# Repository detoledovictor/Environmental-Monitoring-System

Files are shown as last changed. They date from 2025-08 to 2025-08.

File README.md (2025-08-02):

# Environmental Monitoring System

This project is a real-time environmental and motion monitoring system based on the ESP32 with FreeRTOS. It features a TFT display, Wi-Fi connectivity, temperature and acceleration sensing, and visual status indication via an RGB LED.

## 🔧 Features

- 📶 Wi-Fi connection with automatic reconnection
- 🌐 NTP time synchronization (UTC-3)
- 🌡️ Temperature reading (BMP280)
- 🧭 3-axis acceleration monitoring (MMA8452Q)
- 🖥️ 240x240 TFT display with 7-segment styled digital clock
- 🎨 Graphical display of data with FreeRTOS-controlled tasks
- 🔴🟡🟢 RGB LED status indicator using FastLED

## ⚙️ Architecture

- Multitasking with FreeRTOS (`TaskWiFiConnect`, `TaskDateTime`, `TaskReadSensors`, etc.)
- Inter-task communication via `QueueHandle_t`
- Display rendering protected by `SemaphoreHandle_t`

## 📚 Dependencies

- [TFT_eSPI](https://github.com/Bodmer/TFT_eSPI)
- [FastLED](https://github.com/FastLED/FastLED)
- [Adafruit BMP280 Library](https://github.com/adafruit/Adafruit_BMP280_Library)
- [RoboCore MMA8452Q](https://github.com/RoboCore/MMA8452Q)
- `WiFi.h`, `NTPClient.h`, `Wire.h`, `SPI.h`

## 📦 Hardware

- ESP32 Dev Module
- 1x TFT 240x240 display (SPI)
- 1x BMP280 sensor (I2C)
- 1x MMA8452Q accelerometer (I2C)
- 1x RGB LED (Neopixel - GPIO 19)

## 📸 Preview

> [Add image or GIF here of the display in action]

## 🛠️ Setup

1. Install libraries listed above via Library Manager or git.
2. Connect peripherals according to pin mapping.
3. Set your Wi-Fi credentials in the code (`ssid`, `password`).
4. Upload using Arduino IDE or PlatformIO.

## 📄 License

MIT License

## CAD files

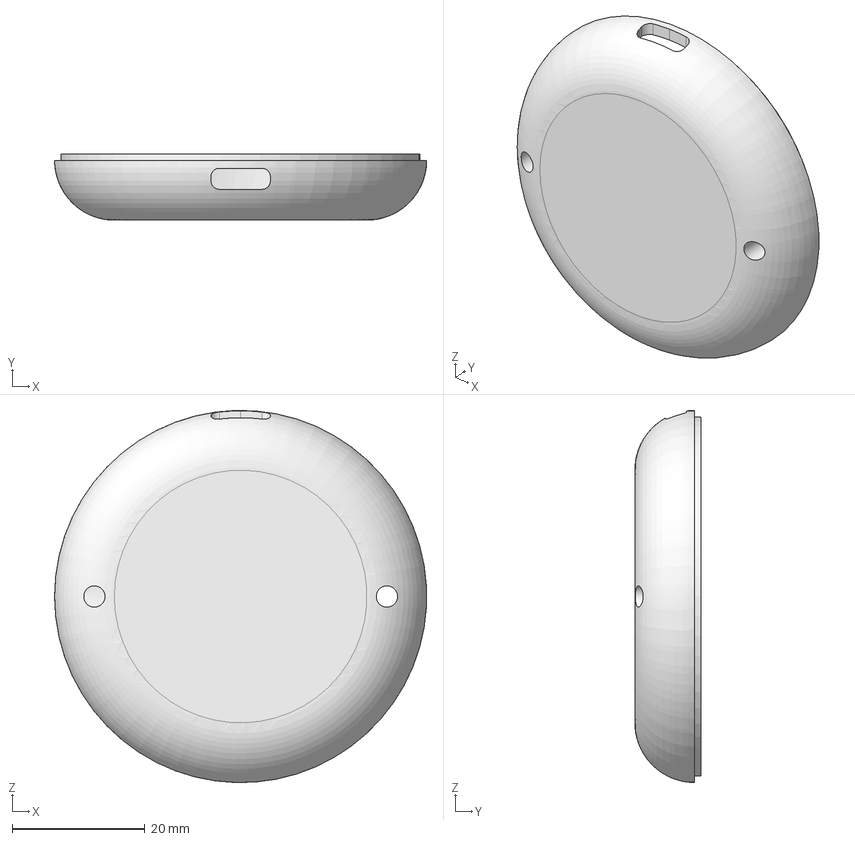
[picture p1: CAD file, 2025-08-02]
MCAD/moldura_001-BASE.step
56.0 x 10.00 x 56.0 mm

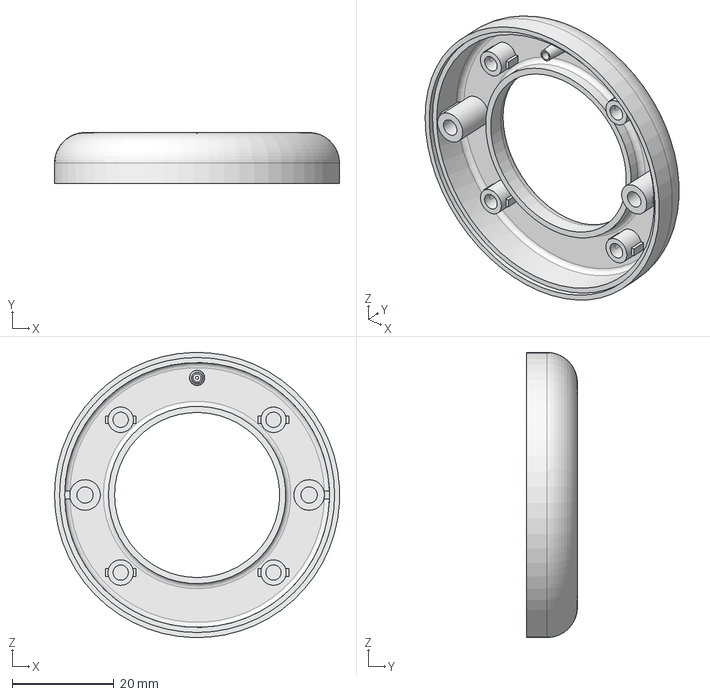
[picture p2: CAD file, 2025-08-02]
MCAD/moldura_001-TAMPA.step
56.0 x 10.0 x 56.0 mm

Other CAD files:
MCAD/Environmental Monitoring Enclosure.FCStd
MCAD/moldura_001-BASE.stl
MCAD/moldura_001-TAMPA.stl

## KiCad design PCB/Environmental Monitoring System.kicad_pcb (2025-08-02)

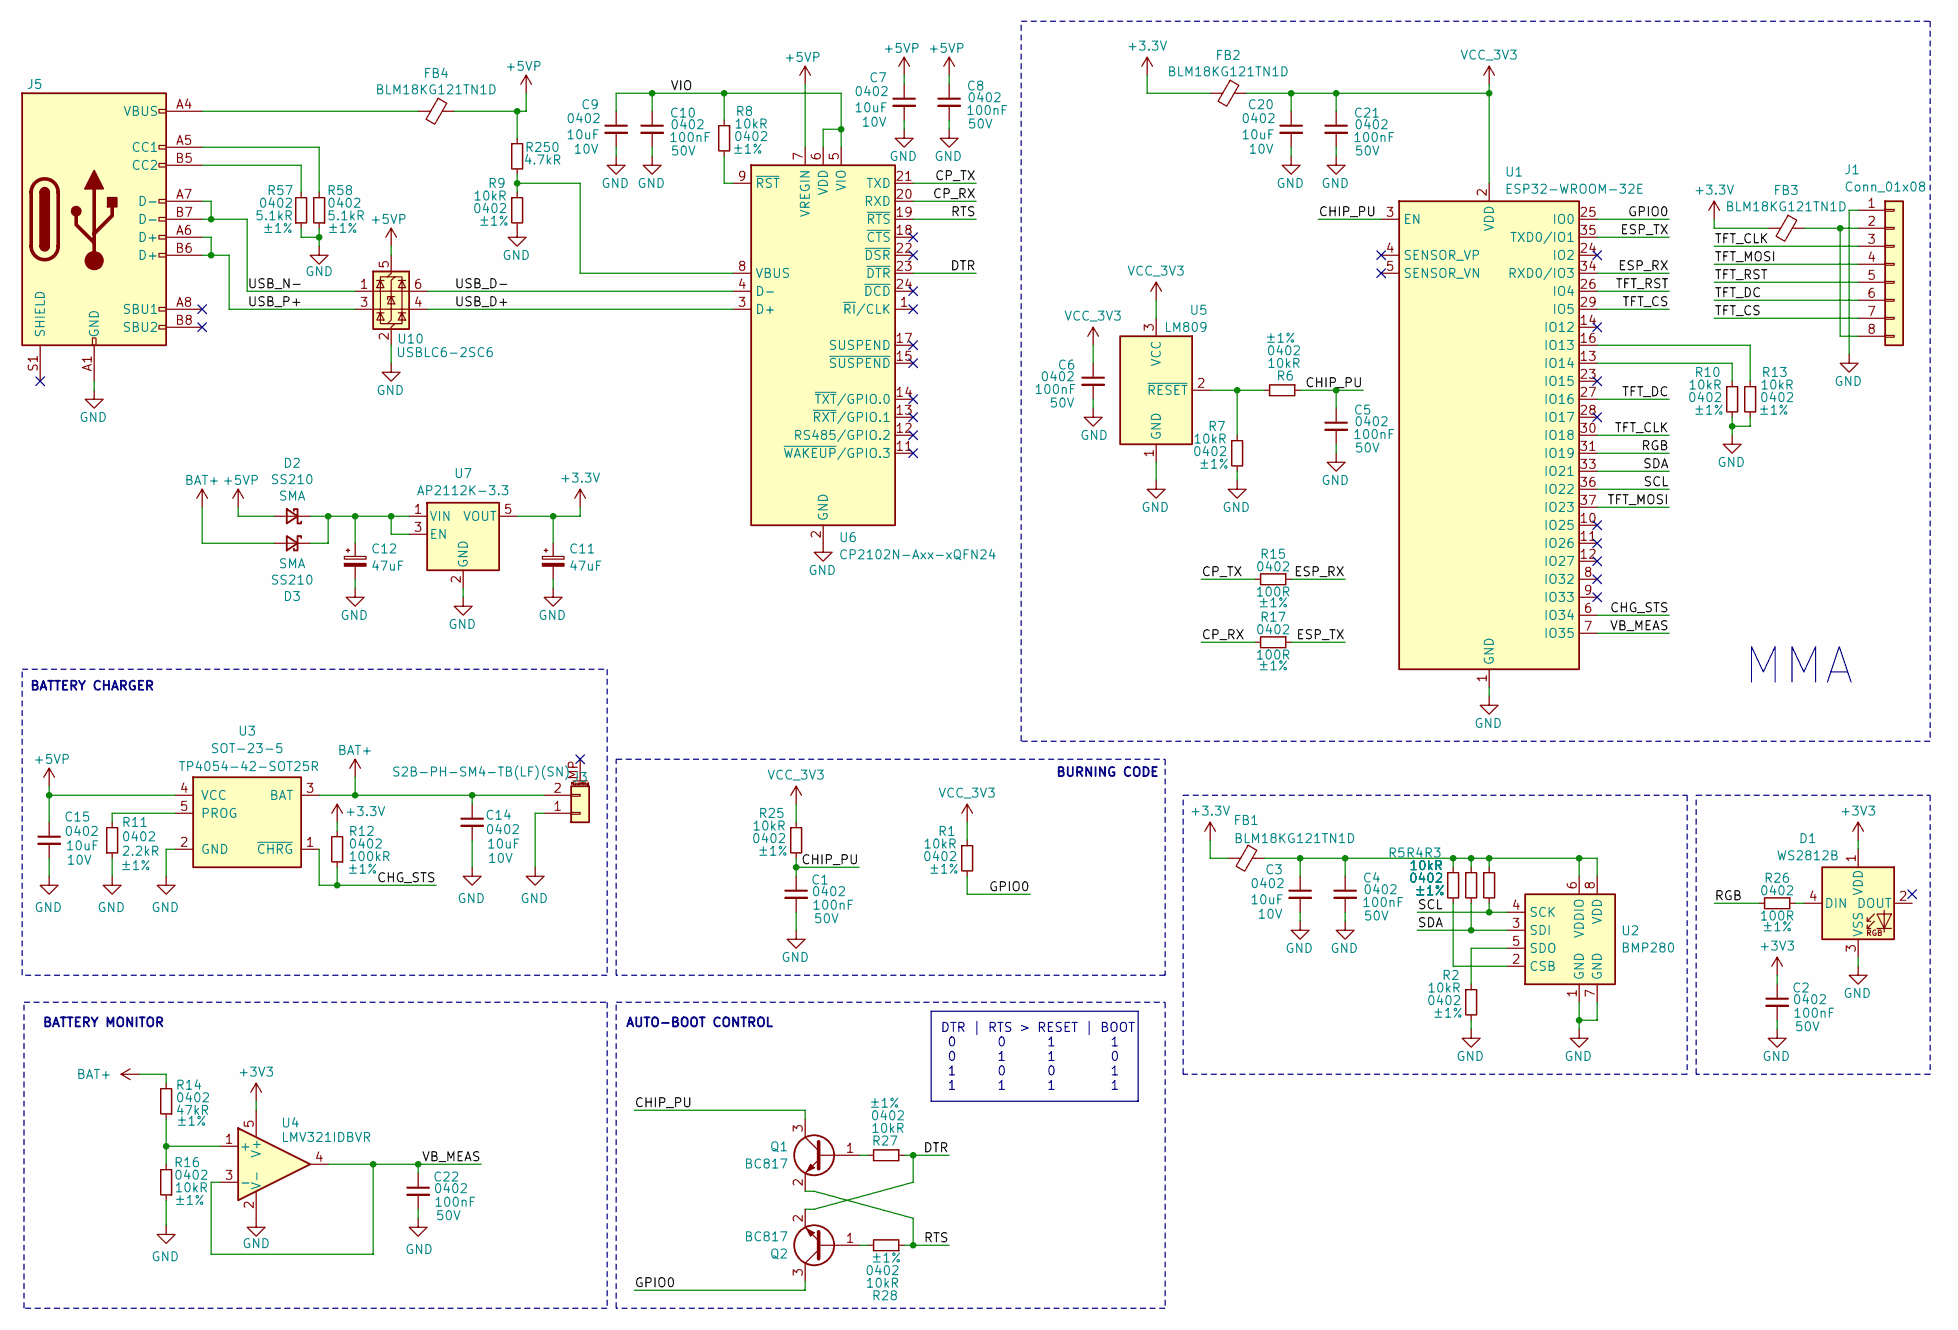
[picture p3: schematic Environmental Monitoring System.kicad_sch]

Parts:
C1, C2, C4, C5, C6, C8, C10, C21, C22: 100nF; C_0402_1005Metric; Voltage 50V; Part CL05B104KB5NNNC; LCSC C960916
C3, C7, C9, C14, C15, C20: 10uF; C_0402_1005Metric; Voltage 10V; Part CL05A106MP5NUNC; LCSC C315248
C11, C12: 47uF; CP_EIA-3216-18_Kemet-A
D1: WS2812B; LED_WS2812B-Mini_PLCC4_3.5x3.5mm
D2, D3: SS210; D_SMA; Voltage 100V; Part SS210; LCSC C14996
FB1, FB2, FB3, FB4: BLM18KG121TN1D; L_0603_1608Metric; Part BLM18KG121TN1D; LCSC C85831
J1: Conn_01x08; PinHeader_1x08_P2.54mm_Vertical
J3: S2B-PH-SM4-TB(LF)(SN); JST_PH_B2B-PH-K_1x02_P2.00mm_Vertical; Part S2B-PH-SM4-TB(LF)(SN); LCSC C295747
J5: USB_C_Receptacle_USB2.0_16P; USB_C_Receptacle_GCT_USB4105-xx-A_16P_TopMnt_Horizontal; Part TYPE-C 16PIN 2MD(073); LCSC C2765186
Q1, Q2: BC817; SOT-23
R1, R2, R3, R4, R5, R6, R7, R8, R9, R10, R13, R16, R25, R27, R28: 10KR; R_0402_1005Metric; Tolerance ±1%; Part 0402WGF1002TCE; LCSC C25744
R11: 2.2KR; R_0402_1005Metric; Tolerance ±1%; Part 0402WGF2201TCE; LCSC C25879
R12: 100KR; R_0402_1005Metric; Tolerance ±1%; Part 0402WGF1003TCE; LCSC C25741
R14: 47KR; R_0402_1005Metric; Tolerance ±1%; Part 0402WGF4702TCE; LCSC C25792
R15, R17, R26: 100R; R_0402_1005Metric; Tolerance ±1%; Part 0402WGF1000TCE; LCSC C25076
R57, R58: 5.1KR; R_0402_1005Metric; Tolerance ±1%; Part 0402WGF5101TCE; LCSC C25905
R250: 4.7kR; R_0402_1005Metric; Tolerance ±1%; Part 0402WGF4701TCE; LCSC C25900
U1: ESP32-WROOM-32E; ESP32-WROOM-32D
U2: BMP280; Bosch_LGA-8_2x2.5mm_P0.65mm_ClockwisePinNumbering
U3: TP4054; SOT-23-5; Part TP4054-42-SOT25R; LCSC C32574
U4: LMV321; SOT-23-5; Part LMV321IDBVR; LCSC C3014306
U5: LM809; SOT-23
U6: CP2102N-Axx-xQFN24; QFN-24-1EP_4x4mm_P0.5mm_EP2.6x2.6mm; Part CP2102N-A02-GQFN24R; LCSC C969151
U7: AP2112K-3.3; SOT-23-5
U10: USBLC6-2SC6; SOT-23-6; Part USBLC6-2SC6; LCSC C7519

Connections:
+3.3V: C11.1, FB1.2, FB2.2, FB3.2, R12.2, U7.5 (VOUT)
+3V3: C2.1, D1.1 (VDD), U4.5 (V+)
+5VP: C7.1, C8.1, C15.1, D2.2 (A), FB4.1, R250.1, U3.4 (VCC), U6.7 (VREGIN), U10.5 (VBUS)
/CHG_STS: R12.1, U1.6 (IO34), U3.1 (~CHRG)
/CHIP_PU: C1.1, C5.1, Q1.3 (C), R6.1, R25.2, U1.3 (EN)
/CP_RX: R17.2, U6.20 (RXD)
/CP_TX: R15.2, U6.21 (TXD)
/DTR: Q2.2 (E), R27.1, U6.23 (~DTR)
/ESP_RX: R15.1, U1.34 (RXD0/IO3)
/ESP_TX: R17.1, U1.35 (TXD0/IO1)
/GPIO0: Q2.3 (C), R1.2, U1.25 (IO0)
/RGB: R26.2, U1.31 (IO19)
/RTS: Q1.2 (E), R28.1, U6.19 (~RTS)
/SCL: R3.2, U1.36 (IO22), U2.4 (SCK)
/SDA: R4.2, U1.33 (IO21), U2.3 (SDI)
/TFT_CLK: J1.3, U1.30 (IO18)
/TFT_CS: J1.7, U1.29 (IO5)
/TFT_DC: J1.6, U1.27 (IO16)
/TFT_MOSI: J1.4, U1.37 (IO23)
/TFT_RST: J1.5, U1.26 (IO4)
/USB_D+: U6.3 (D+), U10.4 (I/O2)
/USB_D-: U6.4 (D-), U10.6 (I/O1)
/USB_N-: J5.A7 (D-), J5.B7 (D-), U10.1 (I/O1)
/USB_P+: J5.A6 (D+), J5.B6 (D+), U10.3 (I/O2)
/VB_MEAS: C22.1, U1.7 (IO35), U4.3 (-), U4.4
/VIO: C9.1, C10.1, R8.1, U6.5 (VIO), U6.6 (VDD)
BAT+: C14.1, D3.2 (A), J3.2, R14.2, U3.3 (BAT)
GND: C1.2, C2.2, C3.2, C4.2, C5.2, C6.2, C7.2, C8.2, C9.2, C10.2, C11.2, C12.2, C14.2, C15.2, C20.2, C21.2, C22.2, D1.3 (VSS), J1.1, J3.1, J5.A1 (GND), J5.A12 (GND), J5.B1 (GND), J5.B12 (GND), R2.2, R7.2, R9.2, R10.2, R11.1, R13.2, R16.1, R57.1, R58.1, U1.1 (GND), U1.15 (GND), U1.38 (GND), U1.39 (GND), U2.1 (GND), U2.7 (GND), U3.2 (GND), U4.2 (V-), U5.1 (GND), U6.2 (GND), U6.25 (GND), U7.2 (GND), U10.2 (GND)
unnamed: D1.4 (DIN), R26.1
unnamed: C12.1, D2.1 (K), D3.1 (K), U7.1 (VIN), U7.3 (EN)
unnamed: FB4.2, J5.A4 (VBUS), J5.A9 (VBUS), J5.B4 (VBUS), J5.B9 (VBUS)
unnamed: FB3.1, J1.2, J1.8
unnamed: J5.A5 (CC1), R58.2
unnamed: J5.B5 (CC2), R57.2
unnamed: Q1.1 (B), R27.2
unnamed: Q2.1 (B), R28.2
unnamed: R13.1, U1.16 (IO13)
unnamed: R10.1, U1.13 (IO14)
unnamed: R5.2, U2.2 (CSB)
unnamed: R2.1, U2.5 (SDO)
unnamed: C3.1, C4.1, FB1.1, R3.1, R4.1, R5.1, U2.6 (VDDIO), U2.8 (VDD)
unnamed: R11.2, U3.5 (PROG)
unnamed: R14.1, R16.2, U4.1 (+)
unnamed: R6.2, R7.1, U5.2 (~RESET)
unnamed: R9.1, R250.2, U6.8 (VBUS)
unnamed: R8.2, U6.9 (~RST)
VCC_3V3: C6.1, C20.1, C21.1, FB2.1, R1.1, R25.1, U1.2 (VDD), U5.3 (VCC)

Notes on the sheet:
DTR | RTS > RESET | BOOT 0 0 1 1 0 1 1 0 1 0 0 1 1 1 1 1
BATTERY CHARGER
AUTO-BOOT CONTROL
BURNING CODE
MMA
BATTERY MONITOR

Board: 2 copper layers, 61 parts (4 on the bottom side), 47 nets, no tracks yet.

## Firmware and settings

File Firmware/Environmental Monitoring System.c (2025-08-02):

#include <Arduino.h>
#include "freertos/FreeRTOS.h"
#include "freertos/task.h"
#include "freertos/queue.h"
#include "freertos/semphr.h"
#include <Wire.h>
#include <SPI.h>
#include <TFT_eSPI.h>
#include "RoboCore_MMA8452Q.h"
#include <Adafruit_BMP280.h>
#include <WiFi.h>
#include <NTPClient.h>
#include <WiFiUdp.h>
#include <FastLED.h>

// Configurações do Display TFT
TFT_eSPI tft = TFT_eSPI(240, 240);

// Configurações do LED RGB
#define NUM_LEDS 1
#define DATA_PIN 19
#define LED_UPDATE_INTERVAL 50  // ms
CRGB leds[NUM_LEDS];

// Configurações Wi-Fi
const char *ssid = "[Your_SSID]";
const char *password = "[YOUR_PASSWORD]";

// Configurações NTP
WiFiUDP ntpUDP;
NTPClient timeClient(ntpUDP, "pool.ntp.org", -3 * 3600);  // UTC-3 (Brasília)

// Arrays para dias da semana
String diasSemana[] = { "Dom", "Seg", "Ter", "Qua", "Qui", "Sex", "Sab" };

MMA8452Q accelerometer;
Adafruit_BMP280 bmp;

// Estrutura para dados do display
typedef struct {
  String line1;  // Data e hora
  String line2;  // Temperatura
  float accel_x;
  float accel_y;
  float accel_z;
  String line6;  // Status WiFi
} DisplayData;

// Fila para comunicação entre tarefas
QueueHandle_t displayQueue;
DisplayData currentDisplayData;  // Mantém o estado atual do display

SemaphoreHandle_t displayMutex = xSemaphoreCreateMutex();

// Protótipos das tarefas
void TaskBlink(void *pvParameters);
void TaskReadSensors(void *pvParameters);
void TaskWiFiConnect(void *pvParameters);
void TaskDateTime(void *pvParameters);
void TaskUpdateDisplay(void *pvParameters);
void TaskUpdateLED(void *pvParameters);

// Protótipos das funções de desenho
void desenharHorarioSegmentos(const String &timeStr);
void desenharData(const String &dateStr);
void desenharTempUmidade(const String &tempStr);
void desenharAcelerometro(float x, float y, float z);
void desenharIndicadorAcelerometro(float x, float y);
void desenharDigito7Seg(int digito, int x, int y);

void setup() {
  Serial.begin(115200);
  pinMode(2, OUTPUT);

  // Inicializa o LED RGB
  FastLED.addLeds<NEOPIXEL, DATA_PIN>(leds, NUM_LEDS);
  leds[0] = CRGB::Black;
  FastLED.show();

  // Inicializa I2C
  Wire.begin(21, 22);  // SDA, SCL

  // Inicializa o display TFT
  tft.begin();
  tft.setRotation(0);
  tft.fillScreen(TFT_BLACK);

  // Inicializa o acelerômetro
  if (!accelerometer.init()) {
    Serial.println("Falha na inicialização do acelerômetro");
    while (1)
      ;
  }

  // Inicializa o BMP280
  if (!bmp.begin(0x76)) {
    Serial.println("Falha na inicialização do BMP280!");
    while (1)
      ;
  }

  // Cria a fila para o display
  displayQueue = xQueueCreate(5, sizeof(DisplayData));

  // Inicializa a estrutura de dados do display
  currentDisplayData = DisplayData();

  // Cria as tarefas
  xTaskCreate(TaskBlink, "Blink", 2048, NULL, 1, NULL);
  xTaskCreate(TaskReadSensors, "Sensors", 4096, NULL, 2, NULL);
  xTaskCreate(TaskWiFiConnect, "WiFiConnect", 8192, NULL, 3, NULL);
  xTaskCreate(TaskDateTime, "DateTime", 4096, NULL, 2, NULL);
  xTaskCreate(TaskUpdateDisplay, "Display", 4096, NULL, 3, NULL);
  xTaskCreate(TaskUpdateLED, "LED", 2048, NULL, 2, NULL);
}

void loop() {
  // Nada aqui - tudo é tratado pelas tarefas
}

// Tarefa: Piscar LED onboard
void TaskBlink(void *pvParameters) {
  for (;;) {
    digitalWrite(2, !digitalRead(2));
    vTaskDelay(500 / portTICK_PERIOD_MS);
  }
}

// Tarefa: Leitura de sensores
void TaskReadSensors(void *pvParameters) {
  DisplayData data;

  for (;;) {
    // Lê acelerômetro
    accelerometer.read();
    data.accel_x = accelerometer.x;
    data.accel_y = accelerometer.y;
    data.accel_z = accelerometer.z;

    // Lê temperatura
    float temperature = bmp.readTemperature();
    data.line2 = String(temperature, 1);

    // Envia dados para a fila
    xQueueSend(displayQueue, &data, portMAX_DELAY);

    vTaskDelay(100 / portTICK_PERIOD_MS);
  }
}

// Tarefa: Conexão Wi-Fi
void TaskWiFiConnect(void *pvParameters) {
  DisplayData data;

  data.line6 = "Conectando WiFi...";
  xQueueSend(displayQueue, &data, portMAX_DELAY);

  WiFi.begin(ssid, password);

  int attempts = 0;
  while (WiFi.status() != WL_CONNECTED && attempts < 20) {
    vTaskDelay(500 / portTICK_PERIOD_MS);
    Serial.print(".");
    attempts++;
  }

  if (WiFi.status() == WL_CONNECTED) {
    data.line6 = "WiFi OK";
    xQueueSend(displayQueue, &data, portMAX_DELAY);

    // Mantém a conexão ativa
    for (;;) {
      if (WiFi.status() != WL_CONNECTED) {
        WiFi.reconnect();
        data.line6 = "Reconectando...";
        xQueueSend(displayQueue, &data, portMAX_DELAY);
        vTaskDelay(5000 / portTICK_PERIOD_MS);
      }
      vTaskDelay(1000 / portTICK_PERIOD_MS);
    }
  } else {
    data.line6 = "WiFi Falhou!";
    xQueueSend(displayQueue, &data, portMAX_DELAY);
    vTaskDelay(5000 / portTICK_PERIOD_MS);
    ESP.restart();
  }
}

// Tarefa: Data e Hora
void TaskDateTime(void *pvParameters) {
  DisplayData data;

  // Espera conexão Wi-Fi
  while (WiFi.status() != WL_CONNECTED) {
    vTaskDelay(1000 / portTICK_PERIOD_MS);
  }

  timeClient.begin();

  for (;;) {
    timeClient.update();

    // Formata data e hora
    String dayOfWeek = diasSemana[timeClient.getDay()];
    time_t epochTime = timeClient.getEpochTime();
    struct tm *ptm = gmtime(&epochTime);

    // Formata a hora (HH:MM)
    int hours = timeClient.getHours();
    int minutes = timeClient.getMinutes();
    String formattedTime = String(hours < 10 ? "0" : "") + String(hours) + ":" + String(minutes < 10 ? "0" : "") + String(minutes);

    // Formata a data (DD/MM/YYYY)
    String formattedDate = String(ptm->tm_mday) + "/" + String(ptm->tm_mon + 1) + "/" + String(ptm->tm_year + 1900);

    // Combina tudo
    data.line1 = formattedTime + "|" + dayOfWeek + "," + formattedDate;

    xQueueSend(displayQueue, &data, portMAX_DELAY);
    vTaskDelay(1000 / portTICK_PERIOD_MS);
  }
}

// Tarefa: Atualização centralizada do display
void TaskUpdateDisplay(void *pvParameters) {
  DisplayData newData;
  unsigned long lastUpdate = 0;
  const unsigned long updateInterval = 10;  // ms

  for (;;) {
    unsigned long now = millis();

    // Verifica se há novos dados na fila
    if (xQueueReceive(displayQueue, &newData, 0) == pdTRUE) {
      // Atualiza apenas os campos que receberam novos dados
      if (!newData.line1.isEmpty()) currentDisplayData.line1 = newData.line1;
      if (!newData.line2.isEmpty()) currentDisplayData.line2 = newData.line2;
      if (newData.accel_x != 0 || newData.accel_y != 0 || newData.accel_z != 0) {
        currentDisplayData.accel_x = newData.accel_x;
        currentDisplayData.accel_y = newData.accel_y;
        currentDisplayData.accel_z = newData.accel_z;
      }
      if (!newData.line6.isEmpty()) currentDisplayData.line6 = newData.line6;
    }

    // Atualiza o display apenas no intervalo definido
    if (now - lastUpdate >= updateInterval) {
      lastUpdate = now;

      if (xSemaphoreTake(displayMutex, pdMS_TO_TICKS(100)) == pdTRUE) {
        // Limpa apenas a área necessária em vez de toda a tela
        tft.fillRect(0, 0, 240, 240, TFT_BLACK);

        // Extrai partes da linha 1 (formato: HH:MM|Dia,DD/MM/YYYY)
        int separatorPos = currentDisplayData.line1.indexOf('|');
        String timeStr = currentDisplayData.line1.substring(0, separatorPos);
        String dateStr = currentDisplayData.line1.substring(separatorPos + 1);

        // Desenha os componentes
        desenharHorarioSegmentos(timeStr);
        desenharData(dateStr);

        if (!currentDisplayData.line2.isEmpty()) {
          desenharTempUmidade(currentDisplayData.line2);
        }

        desenharAcelerometro(currentDisplayData.accel_x, currentDisplayData.accel_y, currentDisplayData.accel_z);
        desenharIndicadorAcelerometro(currentDisplayData.accel_x, currentDisplayData.accel_y);

        xSemaphoreGive(displayMutex);
      }
    }
    vTaskDelay(50 / portTICK_PERIOD_MS);
  }
}

// Tarefa: Atualização do LED RGB
void TaskUpdateLED(void *pvParameters) {
  String lastWiFiStatus = "";

  for (;;) {
    // Verifica o status atual do WiFi
    String currentStatus = currentDisplayData.line6;

    // Só atualiza o LED se o status mudou
    if (currentStatus != lastWiFiStatus) {
      lastWiFiStatus = currentStatus;

      if (currentStatus == "WiFi OK") {
        // Verde sólido quando conectado
        leds[0] = CRGB::Green;
        FastLED.show();
      } else if (currentStatus.startsWith("Conectando") || currentStatus.startsWith("Reconectando")) {
        leds[0] = CRGB::Yellow;
        FastLED.show();
      } else {
        leds[0] = CRGB::Red;
        FastLED.show();
      }
    }

    vTaskDelay(LED_UPDATE_INTERVAL / portTICK_PERIOD_MS);
  }
}

// Funções de desenho
void desenharHorarioSegmentos(const String &timeStr) {
  int startX = 120 - 80;
  int startY = 35;

  // Extrai horas e minutos da string
  int horas = timeStr.substring(0, 2).toInt();
  int minutos = timeStr.substring(3, 5).toInt();

  // Desenha cada dígito separadamente
  desenharDigito7Seg(horas / 10, startX, startY);
  desenharDigito7Seg(horas % 10, startX + 40, startY);

  // Dois pontos
  if ((millis() / 500) % 2 == 0) {
    tft.fillRect(startX + 78, startY + 15, 4, 4, TFT_CYAN);
    tft.fillRect(startX + 78, startY + 35, 4, 4, TFT_CYAN);
  }

  desenharDigito7Seg(minutos / 10, startX + 90, startY);
  desenharDigito7Seg(minutos % 10, startX + 130, startY);
}

void desenharData(const String &dateStr) {
  int centroX = 120;
  int y = 90;

  // Configurações de texto
  tft.setTextSize(2);
  tft.setTextColor(TFT_CYAN, TFT_BLACK);

  // Cálculo de largura aproximada
  int larguraTexto = dateStr.length() * 12;

  // Posiciona cursor centralizado e imprime
  tft.setCursor(centroX - larguraTexto / 2, y);
  tft.print(dateStr);
}

void desenharTempUmidade(const String &tempStr) {
  int y = 130;

  // Temperatura
  tft.setTextColor(TFT_WHITE, TFT_BLACK);
  tft.setTextSize(1);
  tft.setCursor(20, y);
  tft.print("Temp: ");
  tft.setTextColor(TFT_RED, TFT_BLACK);
  tft.setTextSize(2);
  tft.print(tempStr);
  tft.print("C");
}

void desenharAcelerometro(float x, float y, float z) {
  int yPos = 165;

  tft.setTextColor(TFT_GREEN, TFT_BLACK);
  tft.setTextSize(1);

  // X
  tft.setCursor(20, yPos);
  tft.print("X: ");
  tft.print(x, 2);

  // Y
  tft.setCursor(90, yPos);
  tft.print("Y: ");
  tft.print(y, 2);

  // Z
  tft.setCursor(160, yPos);
  tft.print("Z: ");
  tft.print(z, 2);
}

void desenharIndicadorAcelerometro(float x, float y) {
  int centroX = 120;
  int centroY = 200;
  int raio = 25;

  // Círculo de referência
  tft.drawCircle(centroX, centroY, raio, TFT_DARKGREY);

  // Ponto representando a inclinação
  int pontoX = centroX + (x * raio * 10);
  int pontoY = centroY + (y * raio * 10);

  // Limita dentro do círculo
  float distancia = sqrt(pow(pontoX - centroX, 2) + pow(pontoY - centroY, 2));
  if (distancia > raio) {
    float fator = raio / distancia;
    pontoX = centroX + (pontoX - centroX) * fator;
    pontoY = centroY + (pontoY - centroY) * fator;
  }

  // Desenha o ponto
  tft.fillCircle(pontoX, pontoY, 3, TFT_GREEN);
  tft.fillCircle(centroX, centroY, 2, TFT_WHITE);
}

void desenharDigito7Seg(int digito, int x, int y) {
  bool segmentos[10][7] = {
    { 1, 1, 1, 1, 1, 1, 0 },  // 0
    { 0, 1, 1, 0, 0, 0, 0 },  // 1
    { 1, 1, 0, 1, 1, 0, 1 },  // 2
    { 1, 1, 1, 1, 0, 0, 1 },  // 3
    { 0, 1, 1, 0, 0, 1, 1 },  // 4
    { 1, 0, 1, 1, 0, 1, 1 },  // 5
    { 1, 0, 1, 1, 1, 1, 1 },  // 6
    { 1, 1, 1, 0, 0, 0, 0 },  // 7
    { 1, 1, 1, 1, 1, 1, 1 },  // 8
    { 1, 1, 1, 1, 0, 1, 1 }   // 9
  };

  uint16_t cor = TFT_CYAN;
  uint16_t corOff = TFT_BLACK;

  // Desenha os segmentos
  tft.fillRect(x + 2, y, 26, 4, segmentos[digito][0] ? cor : corOff);        // a
  tft.fillRect(x + 26, y + 2, 4, 22, segmentos[digito][1] ? cor : corOff);   // b
  tft.fillRect(x + 26, y + 26, 4, 22, segmentos[digito][2] ? cor : corOff);  // c
  tft.fillRect(x + 2, y + 46, 26, 4, segmentos[digito][3] ? cor : corOff);   // d
  tft.fillRect(x, y + 26, 4, 22, segmentos[digito][4] ? cor : corOff);       // e
  tft.fillRect(x, y + 2, 4, 22, segmentos[digito][5] ? cor : corOff);        // f
  tft.fillRect(x + 2, y + 23, 26, 4, segmentos[digito][6] ? cor : corOff);   // g
}
